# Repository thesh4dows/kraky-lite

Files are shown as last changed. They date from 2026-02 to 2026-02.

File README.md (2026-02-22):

# Kraky-lite

Kraky lite is a smaller version of kraky focused only on wifi, bluetooth and sub-GHz frequencies.
I've decided to do it so i can learn SMD sodering with a simpler project. 
This project can be used for learning the basics of wifi, bluetooth and sub-GHz frequencies attacks and protections.

---

## Main Components

| Function | Component |
|---|---|
| Logic board | **ESP32-S3 N16R8** |
| Sub-GHz | **CC1101** |
| Wifi/bluetooth | **NFR24L01** |
| Display | **TFT Display** |

---

## Future Features 

- microSD support

---

## WIRING DIAGRAM



---

## PCB 



---

## PCB AND 3D RENDER COMBINED



---

## BOM LIST
| Component | Link |
|---|---|
| **ESP32-S3-N16R8** | [Aliexpress](https://it.aliexpress.com/item/1005006214506085.html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) | 
| **buttons** | [Aliexpress](https://it.aliexpress.com/item/1005003751942617.html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) |
| **tft display** | [Aliexpress](https://www.aliexpress.com/item/1005009234839022.html) |
| **10k ohm** | [Aliexpress](https://it.aliexpress.com/item/1005008049421850.html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) |
| **5.1K ohm** | [Aliexpress](https://it.aliexpress.com/item/1005002705550504.html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) |
| **am51117-3.3** | [Aliexpress](https://it.aliexpress.com/item/1005002487704059.html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) |
| **2345986-1** | [Aliexpress](https://it.aliexpress.com/item/1005007419369264.html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) |
| **100nF** | [Aliexpress](https://it.aliexpress.com/item/1005005691676032.html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) |
| **10uF** | [Aliexpress](https://it.aliexpress.com/item/1005011610443745.html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) |
| **2x4 pin holder** | [Aliexpress](https://it.aliexpress.com/item/1005007049075918.html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) |
| **CC1101** | [Aliexpress](https://it.aliexpress.com/item/1005005200440286.html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) |
| **NFR24L01** | [Aliexpress](https://it.aliexpress.com/item/1005009048175597.html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) |

---

## Responsible Use

Kraky lite is built to make it easier for anyone to explore and understand how multifunction electronic devices work in everyday life.
It’s not intended for bypassing security systems or breaking any laws.

All features are implemented with an educational and experimental focus.

---

## Tools Used

- KiCad 9
- Fusion360
- PlatformIO

---

## Project Status

This project is **work in progress (WIP)**.  
Future updates will include:

- microSD implementation
- firmware development

---

## Contributing

Kraky lite is an **open and educational project**.  
Feedback, suggestions, and improvements are always welcome.

---

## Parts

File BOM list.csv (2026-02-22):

name | link | quantity | price
esp32-s3 n16r8 | https://it.aliexpress.com/item/1005006214506085.html?curPageLogUid=DdOQtJzkOMgO | 1 | 4,39 €
button | https://it.aliexpress.com/item/1005003751942617.html?curPageLogUid=h3YPZfgd06kE | 1 | 2,72 €
tft display | https://www.aliexpress.com/item/1005009234839022.html | 1 | 2,74 €
10K ohm | https://it.aliexpress.com/item/1005008049421850.html?curPageLogUid=0AoDAOfCkDU4 | 1 | 1,47 €
5,1K ohm | https://it.aliexpress.com/item/1005007049075918.html?curPageLogUid=65bfxIdz91Fv | 1 | 1,48 €
am51117-3.3 | https://it.aliexpress.com/item/1005002487704059.html?curPageLogUid=6WlvmG2NNVx1 | 1 | 1,93 €
2345986-1 | https://it.aliexpress.com/item/1005007419369264.html?curPageLogUid=mCOWM8LKrjb6 | 1 | 3,40 €
100nF | https://it.aliexpress.com/item/1005005691676032.html?mp=1 | 1 | 1,45 €
10uF | https://it.aliexpress.com/item/1005011610443745.html?curPageLogUid=OsI94ufdQ7ZQ | 1 | 1,98 €
pin holder | https://it.aliexpress.com/item/1005007049075918.html?curPageLogUid=65bfxIdz91Fv | 1 | 2,10 €
cc1101 | https://it.aliexpress.com/item/1005005200440286.html?curPageLogUid=iVKMPh9qPKnc | 2 | 2,81€x2
nrf24l01 | https://it.aliexpress.com/item/1005009048175597.html?curPageLogUid=PTz4PpO0x6AV | 2 | 2,42€x2

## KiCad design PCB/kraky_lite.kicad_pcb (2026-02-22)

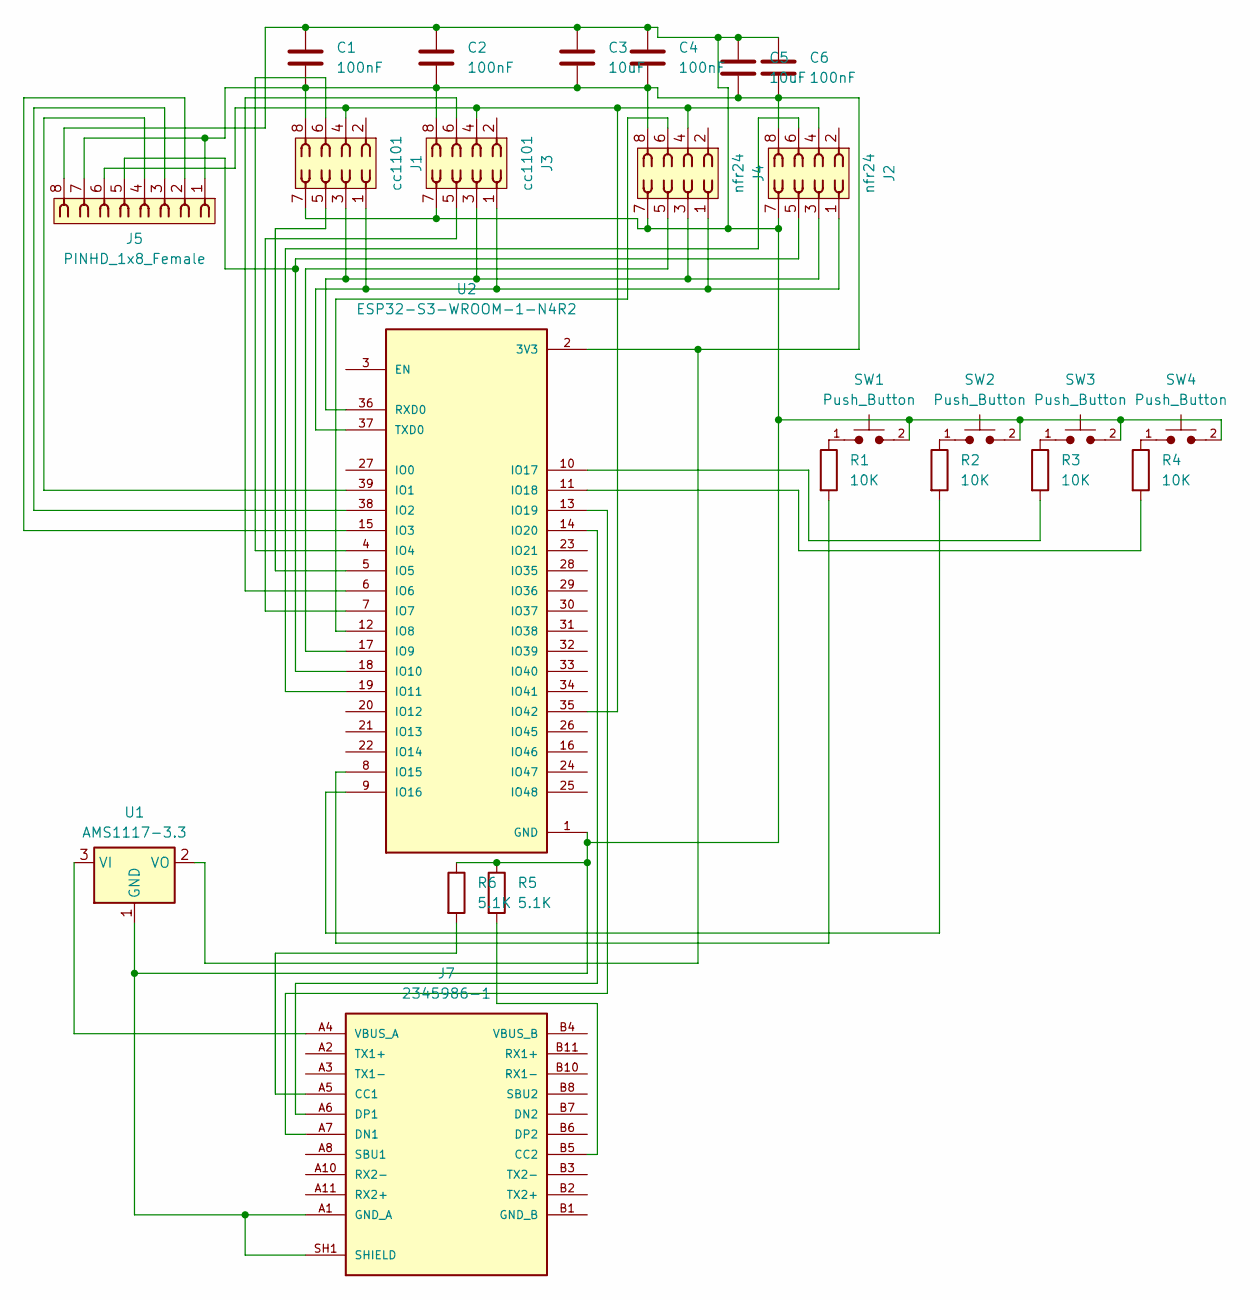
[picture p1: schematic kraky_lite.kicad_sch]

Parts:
C1, C2, C4, C6: 100nF; C_Axial_L3.8mm_D2.6mm_P7.50mm_Horizontal
C3, C5: 10uF; C_Axial_L3.8mm_D2.6mm_P7.50mm_Horizontal
J1, J3: cc1101; PinSocket_2x04_P2.54mm_Vertical
J2, J4: nfr24; PinSocket_2x04_P2.54mm_Vertical
J5: PINHD_1x8_Female; PinSocket_1x08_P2.54mm_Vertical
J7: 2345986-1; TE_2345986-1; PARTREV C
R1, R2, R3, R4: 10K; R_Axial_DIN0204_L3.6mm_D1.6mm_P5.08mm_Horizontal
R5, R6: 5.1K; R_Axial_DIN0204_L3.6mm_D1.6mm_P5.08mm_Horizontal
SW1, SW2, SW3, SW4: Push_Button; SW_PUSH_6mm
U1: AMS1117-3.3; SOT-223-3_TabPin2
U2: ESP32-S3-WROOM-1-N4R2; XCVR_ESP32-S3-WROOM-1-N4R2; PARTREV v1.0

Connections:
GND: C1.1, C2.1, C3.1, C4.1, C5.1, C6.1, J1.7, J2.7, J3.7, J4.7, J5.8, J7.A1 (GND_A), J7.A12 (GND_A), J7.SH1 (SHIELD), J7.SH2 (SHIELD), J7.SH3 (SHIELD), J7.SH4 (SHIELD), R5.1, R6.1, SW1.2, SW2.2, SW3.2, SW4.2, U1.1 (GND), U2.1 (GND), U2.40 (GND), U2.41_1 (GND), U2.41_2 (GND), U2.41_3 (GND), U2.41_4 (GND), U2.41_5 (GND), U2.41_6 (GND), U2.41_7 (GND), U2.41_8 (GND), U2.41_9 (GND)
GND_B: J7.B1 (GND_B), J7.B12 (GND_B)
unnamed: J7.A5 (CC1), R6.2
unnamed: J7.B5 (CC2), R5.2
unnamed: J7.A7 (DN1), U2.13 (IO19)
unnamed: J7.A6 (DP1), U2.14 (IO20)
unnamed: R1.1, SW1.1
unnamed: R2.1, SW2.1
unnamed: R3.1, SW3.1
unnamed: R4.1, SW4.1
unnamed: C1.2, C2.2, C3.2, C4.2, C5.2, C6.2, J1.8, J2.8, J3.8, J4.8, J5.1, J5.7, U1.2 (VO), U2.2 (3V3)
unnamed: J5.4, U2.39 (IO1)
unnamed: J5.3, U2.38 (IO2)
unnamed: J5.2, U2.15 (IO3)
unnamed: J1.6, U2.4 (IO4)
unnamed: J1.5, U2.5 (IO5)
unnamed: J3.6, U2.6 (IO6)
unnamed: J3.5, U2.7 (IO7)
unnamed: J4.6, U2.12 (IO8)
unnamed: J4.5, U2.17 (IO9)
unnamed: J2.5, J5.5, U2.18 (IO10)
unnamed: J2.6, U2.19 (IO11)
unnamed: R1.2, U2.8 (IO15)
unnamed: R2.2, U2.9 (IO16)
unnamed: R3.2, U2.10 (IO17)
unnamed: R4.2, U2.11 (IO18)
unnamed: J1.4, J2.4, J3.4, J4.4, J5.6, U2.35 (IO42)
unnamed: J1.3, J2.3, J3.3, J4.3, U2.36 (RXD0)
unnamed: J1.1, J2.1, J3.1, J4.1, U2.37 (TXD0)
VBUS_A: J7.A4 (VBUS_A), J7.A9 (VBUS_A), U1.3 (VI)
VBUS_B: J7.B4 (VBUS_B), J7.B9 (VBUS_B)

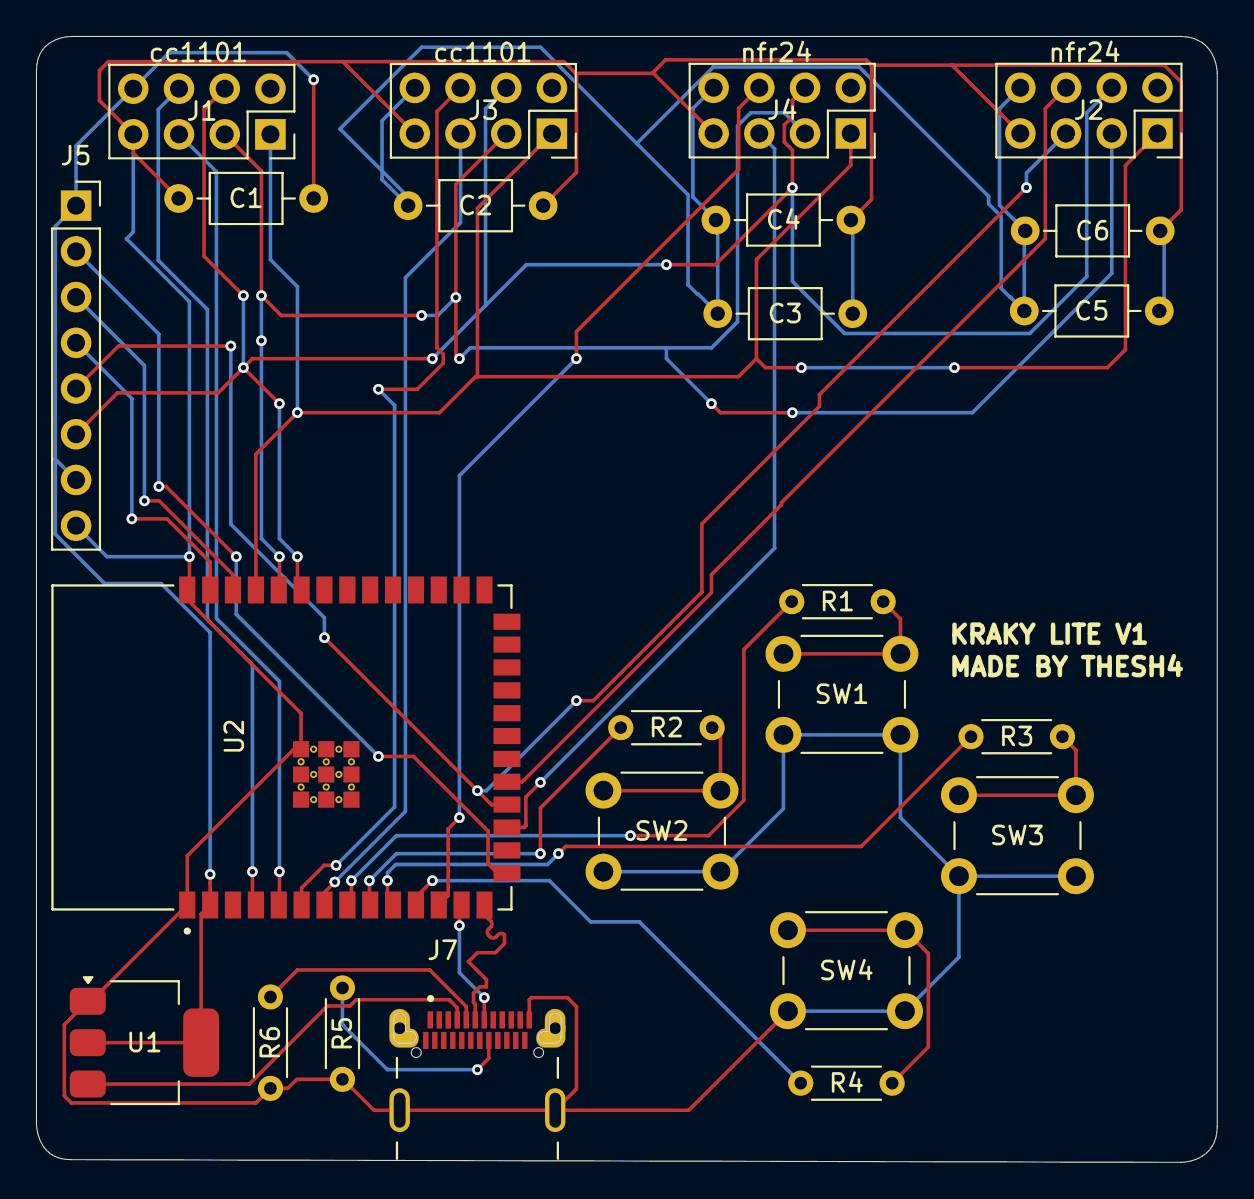
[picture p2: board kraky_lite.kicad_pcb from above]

Board: 2 copper layers, 65.6 x 62.6 mm, 24 parts (0 on the bottom side), 31 nets.

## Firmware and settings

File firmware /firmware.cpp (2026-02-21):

#include <SPI.h>
#include <RF24.h>
#include <ELECHOUSE_CC1101_SRC_DRV.h>
#include <Adafruit_GFX.h>
#include <Adafruit_ST7735.h>

// ---------- SPI PINS ----------
#define MOSI 11
#define MISO 13
#define SCK  12

// ---------- NRF24 ----------
RF24 radio1(4, 5);   // CE, CSN
RF24 radio2(7, 6);   // CE, CSN

// ---------- CC1101 ----------
#define CC1_CS 15
#define CC2_CS 16

// ---------- DISPLAY ----------
#define TFT_CS   10
#define TFT_DC   9
#define TFT_RST  8

Adafruit_ST7735 tft = Adafruit_ST7735(TFT_CS, TFT_DC, TFT_RST);

void setup() {

  Serial.begin(115200);
  delay(2000);

  SPI.begin(SCK, MISO, MOSI);

  Serial.println("=== TEST SISTEMA ===");

  // ---------- DISPLAY ----------
  tft.initR(INITR_BLACKTAB);
  tft.fillScreen(ST77XX_BLACK);
  tft.setTextColor(ST77XX_GREEN);
  tft.setTextSize(1);
  tft.setCursor(0, 0);
  tft.println("BOOT OK");

  // ---------- NRF24 #1 ----------
  tft.println("NRF24 #1...");
  if (radio1.begin()) {
    tft.println("OK");
    Serial.println("NRF24 #1 OK");
  } else {
    tft.println("FAIL");
    Serial.println("NRF24 #1 FAIL");
  }

  // ---------- NRF24 #2 ----------
  tft.println("NRF24 #2...");
  if (radio2.begin()) {
    tft.println("OK");
    Serial.println("NRF24 #2 OK");
  } else {
    tft.println("FAIL");
    Serial.println("NRF24 #2 FAIL");
  }

  // ---------- CC1101 #1 ----------
  tft.println("CC1101 #1...");
  ELECHOUSE_cc1101.setSpiPin(SCK, MISO, MOSI, CC1_CS);
  if (ELECHOUSE_cc1101.getCC1101()) {
    tft.println("OK");
    Serial.println("CC1101 #1 OK");
  } else {
    tft.println("FAIL");
    Serial.println("CC1101 #1 FAIL");
  }

  // ---------- CC1101 #2 ----------
  tft.println("CC1101 #2...");
  ELECHOUSE_cc1101.setSpiPin(SCK, MISO, MOSI, CC2_CS);
  if (ELECHOUSE_cc1101.getCC1101()) {
    tft.println("OK");
    Serial.println("CC1101 #2 OK");
  } else {
    tft.println("FAIL");
    Serial.println("CC1101 #2 FAIL");
  }

  tft.println("TEST COMPLETATO");
}

void loop() {
  // lampeggio per dimostrare che MCU è attivo
  static bool toggle = false;
  toggle = !toggle;

  if (toggle)
    tft.fillRect(100, 120, 20, 20, ST77XX_RED);
  else
    tft.fillRect(100, 120, 20, 20, ST77XX_BLACK);

  delay(500);
}
